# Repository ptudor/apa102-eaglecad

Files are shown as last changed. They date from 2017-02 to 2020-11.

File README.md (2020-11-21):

# apa102 controller

EAGLE schematic and board for apa102 controller

***
## the board

Top:

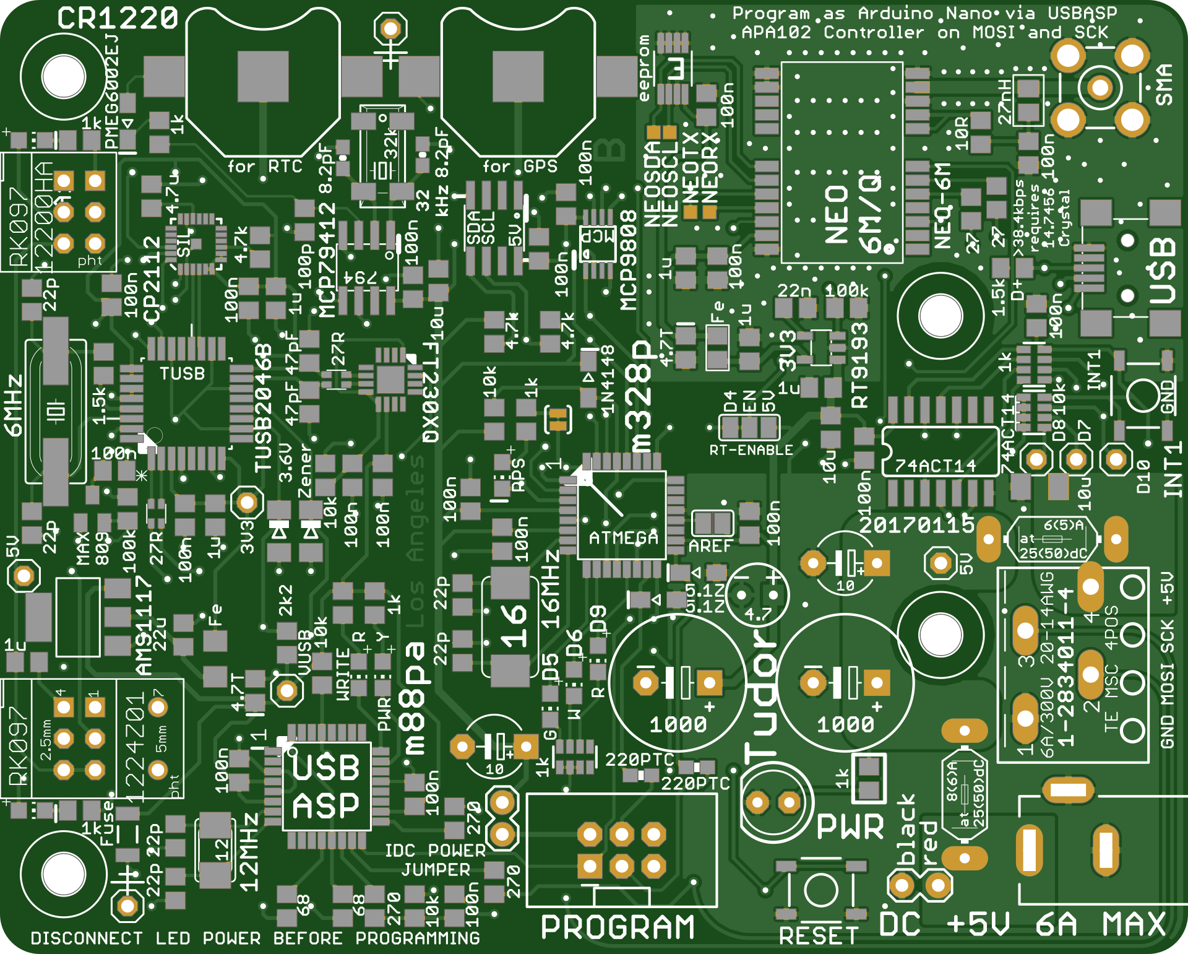
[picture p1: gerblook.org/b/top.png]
PNG of PCB top


Bottom:

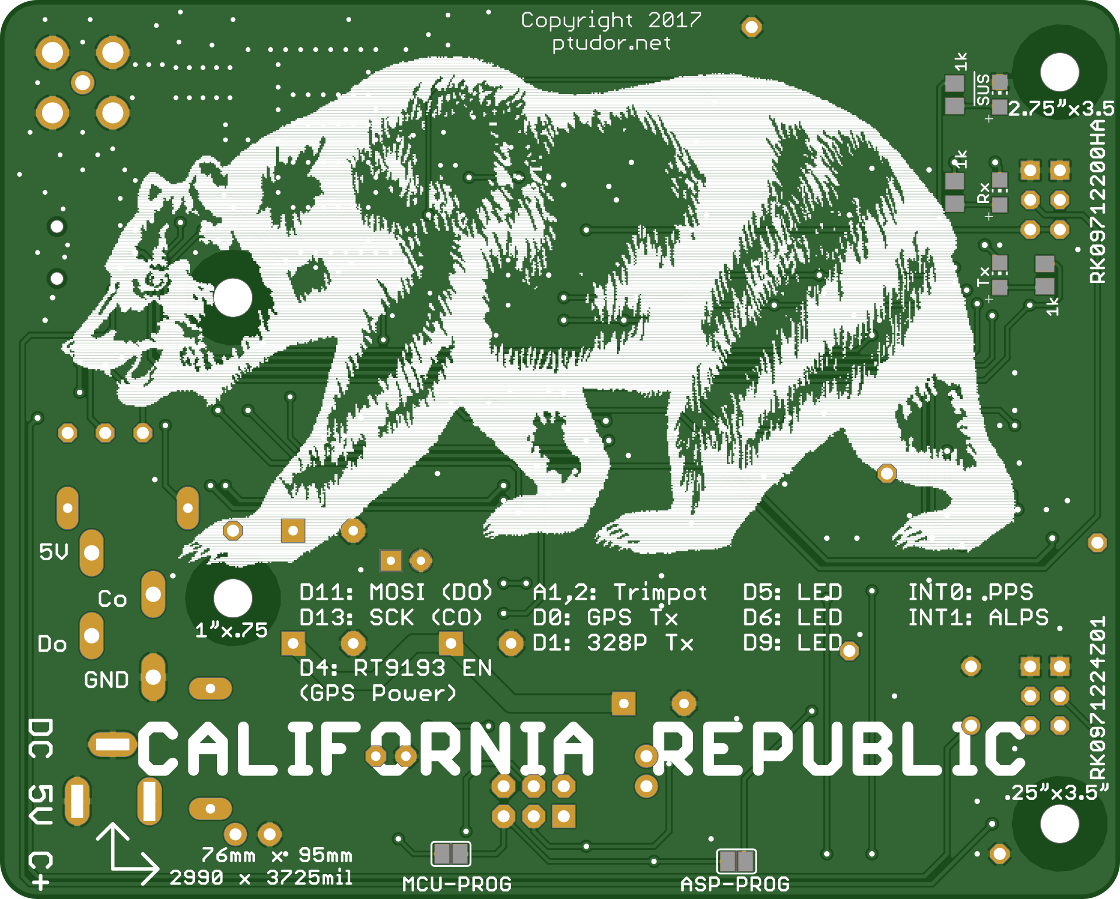
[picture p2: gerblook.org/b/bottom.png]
PNG of PCB bottom

***

## the schematic

#### Power:

DC 5V, AMS1117-3V3, RT9193GB-33.

There is no onboard 5V voltage regulator. Power is supplied by an external switched power supply at 5V with a 2.1mm center positive jack, in a common wall-wart or laptop brick form factor. Two options are available for providing power: Space for a standard rectangular PCB-mount DC jack exists and optionally, to keep those milled slots clean, two holes labelled "red" and "black" are available for use with circular panel mount DC jacks. A fuse follows the voltage input connectors and a second fuse sits between the regular 5V on the PCB and the 5V supplied to the LED connector. Two big electrolytic capacitors sit after the 5V in and before the MCU side and LED side of the power to hopefully prevent brownouts if a strip suddenly changes from off to fully illuminated.

When connected to external USB, the 5V-USB, after a fuse, powers the onboard atmega88p USBASP and FT230X serial directly and runs to an AMS1117 3.3v voltage regulator that serves the USB Hub, CP2112 i2c, and the USB enable on the uBlox GPS. The 3V3 output has the datasheet suggested 22uF capacitor.

The uBlox GPS is powered by an RT9193 3.3v voltage regulator. The enable pin of this device is connected to the primary MCU on pin D4 so it can be turned off in software. Alternatively, a solder jumper permits connecting the pin directly to the primary 5V. The RT9193 has the datasheet recommended 22nF capacitor on the bypass pin for low-noise operation and the 3V3 output passes though a ferrite bead and tantalum capacitor on its way to the integrated circuit.

#### GPS:

A standard uBlox NEO 7M occupies the upper right quadrant of the board. The numerous vias and general layout are hopefully compliant with datasheet requirements. The PPS and TX pins connect to the MCU with RX left disconnected. There is board space for an external eeprom, a cheap and simple part, but it is generally not required.

A CR1220 battery is dedicated to the GPS to enable warm starts. An SMA connection reminds us an external active antenna is required. While the mini-USB connector is nearby, it is not directly connected to the GPS.

#### USB-i2c:

The bridge the gap between computers and the hardware on the circuit board, a CP2112 offers access to the i2c bus.

#### RTC:

Preserving time across reboots, an MCP79408 or MCP79412 is set and periodically synchronized by the GPS. To decouple GPS time and RTC time, the RTC has its own battery so that even if GPS precision is delayed because of a dead-battery cold start, hopefully the RTC has a good idea of at least what the current minute is.

#### MCU:

Basically equivalent in function to an Arduino Nano, the heart of the board is its ATMega328p. It controls the input and output and all those things.

The chip runs at 16MHz with an external crystal. The MOSI and SCK pins are protected with 220 Ohm PTC fuses and 5.1V Zener diodes in the style of Ruggeduino.

Refer to the example program for further details.

#### ISP:

For convenience, an onboard USBASP programmer exists. During assembly and initial configuration be mindful of the solder jumpers on the underside of the PCB connected to the RESET pin of the 6-pin IDC ISP header and the two pins that when jumpered allow USB power to flow to the atmega328p target.

#### USB Hub:

After the board added a fourth USB connector, it became time to just add a hub, the Texas Instruments TUSB2046B. 27 Ohm resistors should be present in the correct places and absent where appropriate. A 1.5k Ohm resistor is connected between USB-3V3 and the external D+ line to signal the device as high speed USB. There is a MAX809S attached on the reset pin to provide the necessary pulse at startup.

#### USB Serial:

A cheaper alternative to the common FT232RL at half the price this board has a FT230X for simple debugging with serial print statements from the MCU. All data pins other than Transmit-Out are disconnected.

#### Connections:

Header for LEDs. Batteries. ISP. USB.

#### Switch Debouncing:

normal hex inverter

#### Input:

ALPS trimpot, ALPS trimpot with switch

#### Temp Sensor:

MCP9808

***

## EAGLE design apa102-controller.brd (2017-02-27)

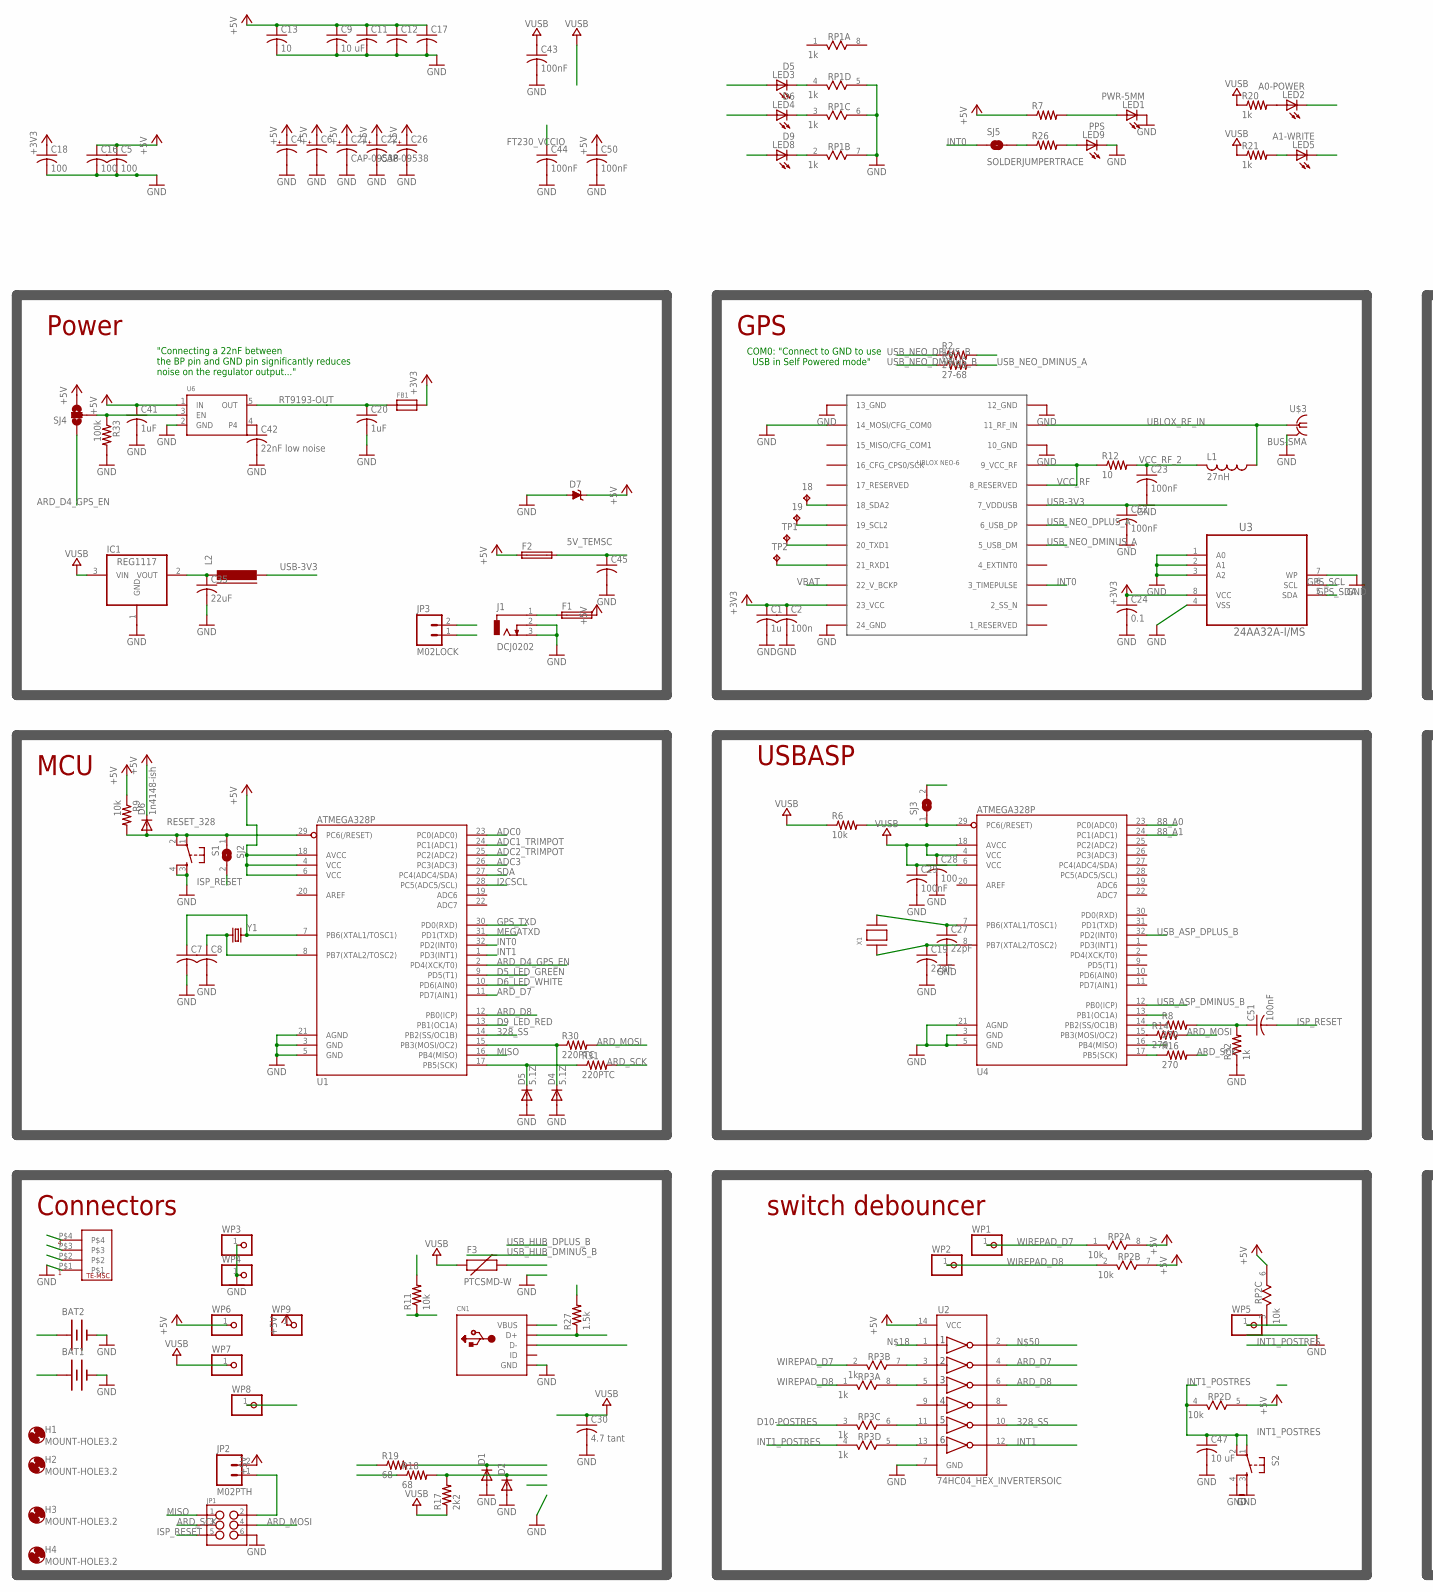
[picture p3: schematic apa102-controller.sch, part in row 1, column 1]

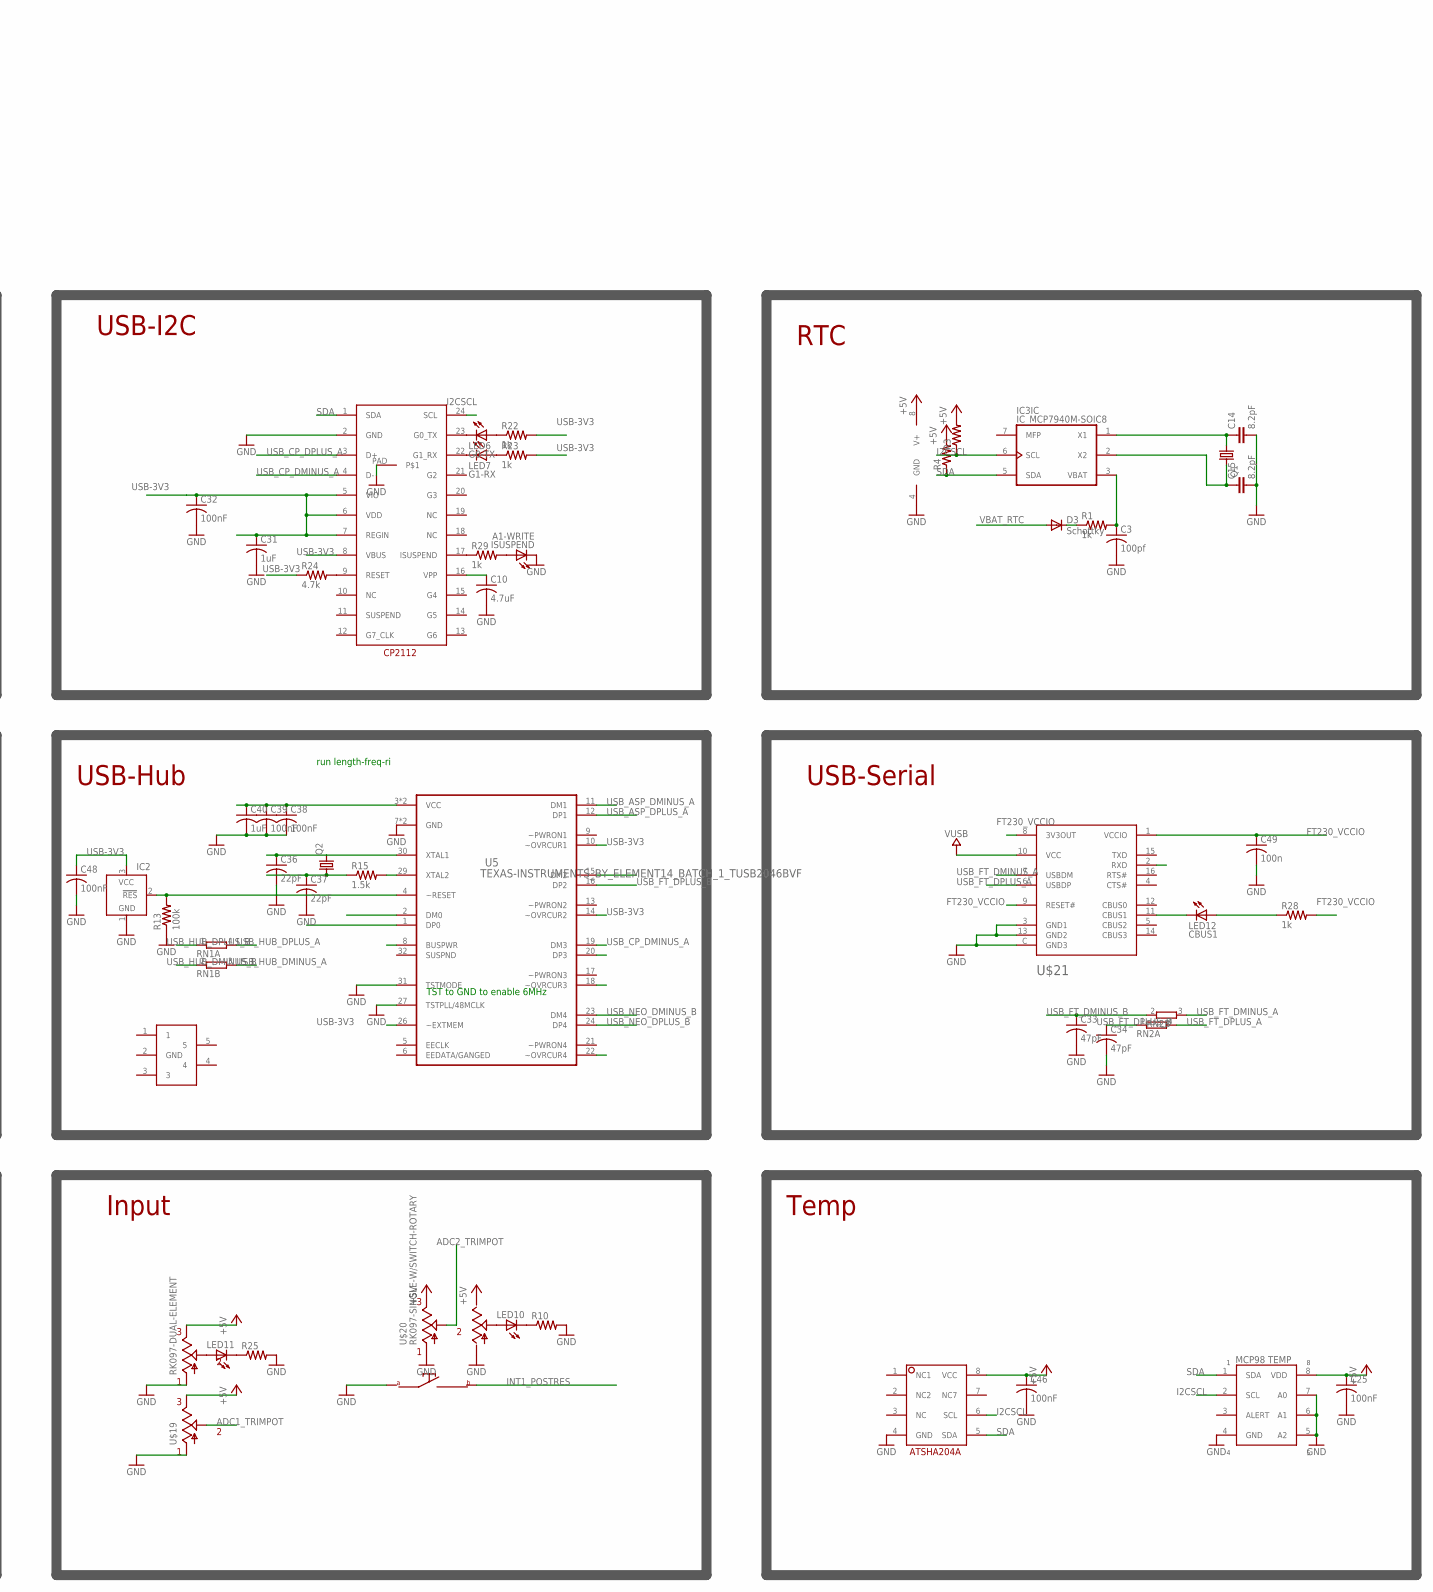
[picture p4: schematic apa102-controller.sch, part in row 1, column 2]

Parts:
18, 19: TPTP10SQ; TP10SQ
BAT1, BAT2: BATTERY12MM; BATTCON_12MM
C1: 1u; C0805
C2, C49: 100n; C0805
C3: 100pf; C0805
C4, C6: CPOL-USE5-5; E5-5
C5, C16, C18, C28: 100; C0805
C7, C8, C11, C12, C17: C-USC0805; C0805
C9, C47: 10 uF; C0805
C10: 4.7uF; C0805
C13: 10; C0805
C14, C15: 8.2pF; 0603-CAP
C19, C27, C36, C37: 22pF; C0805
C20, C31, C40, C41: 1uF; C0805
C21, C22: CAP-09538; CPOL-RADIAL-1000UF-25V
C23, C25, C29, C32, C38, C39, C43, C44, C46, C48, C50, C51, C52: 100nF; C0805
C24: 0.1; C0805
C26: 10UF-25V-20%(PTH)KIT; CPOL-RADIAL-10UF-25V-KIT
C30: 4.7 tant; C0805
C33, C34: 47pF; C0805
C35: 22uF; C0805
C42: 22nF low noise; C0805
C45: C-USC1206K; C1206K
CN1: USBMINIB; USB-MINIB
D1, D2: DIODE-MINIMELF; MINIMELF@1
D3: Schottky; SOD323-W@1
D4, D5: 5.1Z; SOD323-W@1
D6: 1n4148-ish; SOD323-W@1
D7: ZENER-DIODEDO41Z10; DO41Z10
F1, F2: LITTLEFUSE
F3: PTCSMD-W; PTC-1206-WIDE
FB1: FERRITE0805; 0805
H1, H2, H3, H4: MOUNT-HOLE3.2; 3,2
IC1: REG1117; SOT223
IC2: TCM809; SOT23B-3
IC3: IC_MCP7940M-SOIC8; SOIC-8
ISUSPEND: A1-WRITE; CHIP-LED0805
J1: DCJ0202
JP1: M03X2SHROUD; 2X3-SHROUDED
JP2: M02PTH; 1X02
JP3: M02LOCK; 1X02_LOCK
L1: 27nH; M0805
L2: FERRITE-1206; FB1206
LED1: PWR-5MM; LED5MM
LED2: A0-POWER; CHIP-LED0805
LED3: D5; CHIP-LED0805
LED4: D6; CHIP-LED0805
LED5: A1-WRITE; CHIP-LED0805
LED6: G0-TX; CHIP-LED0805
LED7: G1-RX; CHIP-LED0805
LED8: D9; CHIP-LED0805
LED9: PPS; CHIP-LED0805
LED10, LED11: LEDCHIP-LED0805; CHIP-LED0805
LED12: CBUS1; CHIP-LED0805
Q1: CRYSTALMM20SS; MM20SS
Q2: CRYSTALHC49UP; HC49UP
R1, R20, R21, R22, R23, R28, R29, R32: 1k; R0805
R2, R5: 27-68; R0805
R3, R4, R7, R10, R25, R26: R-US_R0805; R0805
R6, R9, R11: 10k; R0805
R8, R14, R16: 270; R0805
R12: 10; R0805
R13, R33: 100k; R0805
R15, R27: 1.5k; R0805
R17: 2k2; R0805
R18, R19: 68; R0805
R24: 4.7k; R0805
R30, R31: 220PTC; 0603-RES
RN1, RN2: 2R-NEXBV4V; EXBV4V
RP1, RP3: 1k; RES4NT
RP2: 10k; RES4NT
S1, S2: TAC_SWITCHSMD; TACTILE-SWITCH-SMD
SJ2, SJ3: SJ
SJ4: SOLDERJUMPER_2WAYT; SJ_2
SJ5: SOLDERJUMPERTRACE; SJ_2S-TRACE
TP1, TP2: TPTP10SQ; TP10SQ
U1, U4: ATMEGA328P; TQFP32-08
U2: 74HC04_HEX_INVERTERSOIC; SOIC-14
U3: 24AA32A-I/MS; SOP65P490X110-8N
U5: TEXAS-INSTRUMENTS_BY_ELEMENT14_BATCH_1_TUSB2046BVF; TEXAS-INSTRUMENTS_BY_ELEMENT14_BATCH_1_QFP80P900X900X145-32N
U6: VREG_SOT23-5; SOT23-5
U$2: UBLOX_NEO-6; UBLOX_NEO-6P
U$3: BUS-SMA
U$7: MCP98; MSOP08
U$11: CP2112; QFN-24
U$17: TE-MSC-4POS-6A
U$18: ATSHA204A; SO08
U$19: RK097-DUAL-ELEMENT
U$20: RK097-SINGLE-W/SWITCH-ROTARY; RK097-DUAL-ELEMENT-W/SWITCH
U$21: FT230XQ; QFN4X4-16
U$23: ESDTUDOR; SOT23-5L
WP1, WP2, WP3, WP4, WP5, WP6, WP7, WP8, WP9: WPAD-1-PTH; WPAD-1-PTH-2.54
X1: XTALNX5032; NX5032
Y1: CRYSTALABM2; CRYSTAL-ABRACON-ABM2

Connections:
5V_TEMSC: C45.1, F2.2, U$17.P$4
88_A0: LED2.C, U4.23 (PC0(ADC0))
88_A1: LED5.C, U4.24 (PC1(ADC1))
328_SS: U1.14 (PB2(SS/OC1B)), U2.10 (5Y)
+3V3: C1.1, C2.1, C18.1, C24.1, FB1.2, U3.8 (VCC), U$2.23_VCC
+5V: C4.+, C5.1, C6.+, C9.1, C11.1, C12.1, C13.1, C16.1, C17.1, C21.+, C22.+, C25.1, C26.1 (+), C41.1, C46.1, C50.1, D6.C, D7.C, F1.2, F2.1, IC3.8 (V+), JP2.2, R3.2, R4.2, R7.1, R9.1, RP2.5 (2), RP2.6 (2), RP2.7 (2), RP2.8 (2), SJ4.3, U1.4 (VCC), U1.6 (VCC), U1.18 (AVCC), U2.14 (VCC), U6.1 (IN), U$7.8 (VDD), U$18.8 (VCC), U$19.P$3 (E1), U$19.P$6 (E), U$20.P$3 (E), U$20.P$6 (E1), WP6.1, WP9.1
ADC0: U1.23 (PC0(ADC0))
ADC1_TRIMPOT: U1.24 (PC1(ADC1)), U$19.P$5 (S1)
ADC2_TRIMPOT: U1.25 (PC2(ADC2)), U$20.P$2 (S)
ADC3: U1.26 (PC3(ADC3))
ARD_D4_GPS_EN: R33.1, SJ4.1, SJ4.2, U1.2 (PD4(XCK/T0)), U6.3 (EN)
ARD_D7: U1.11 (PD7(AIN1)), U2.4 (2Y)
ARD_D8: U1.12 (PB0(ICP)), U2.6 (3Y)
ARD_MOSI: JP1.4, R14.2, R30.2, U$17.P$2
ARD_SCK: JP1.3, R16.2, R31.2, U$17.P$3
D5_LED_GREEN: LED3.A, U1.9 (PD5(T1))
D6_LED_WHITE: LED4.A, U1.10 (PD6(AIN0))
D9_LED_RED: LED8.A, U1.13 (PB1(OC1A))
D10-POSTRES: RP2.3 (1), RP3.3 (1), WP5.1
DCJACK_TO_PTC: F1.1, J1.1, JP3.1
FT230_VCCIO: C44.1, C49.1, R11.2, R28.2, U$21.1 (VCCIO), U$21.8 (3V3OUT), U$21.9 (RESET#)
FT_CB0: LED12.C, U$21.11 (CBUS1)
GND: BAT1.GND (-), BAT2.GND (-), C1.2, C2.2, C3.2, C4.-, C5.2, C6.-, C7.2, C8.2, C9.2, C10.2, C11.2, C12.2, C13.2, C14.2, C15.2, C16.2, C17.2, C18.2, C19.2, C20.2, C21.-, C22.-, C23.2, C24.2, C25.2, C26.2 (-), C27.2, C28.2, C29.2, C30.2, C31.2, C32.2, C33.2, C34.2, C35.2, C36.2, C37.2, C38.2, C39.2, C40.2, C41.2, C42.2, C43.2, C44.2, C45.2, C46.2, C47.2, C48.2, C49.2, C50.2, C52.2, CN1.GND, D1.A, D2.A, D4.A, D5.A, D7.A, IC1.1 (GND), IC2.1 (GND), IC3.4 (GND), ISUSPEND.C, J1.2, J1.3, JP1.6, JP3.2, LED1.K (C), LED9.C, R10.2, R13.1, R25.2, R32.1, R33.2, RP1.5 (2), RP1.6 (2), RP1.7 (2), S1.3, S1.4, S2.3, S2.4, U1.3 (GND), U1.5 (GND), U1.21 (AGND), U2.7 (GND), U3.1 (A0), U3.2 (A1), U3.3 (A2), U3.4 (VSS), U3.7 (WP), U4.3 (GND), U4.5 (GND), U4.21 (AGND), U5.7 (GND), U5.27 (TSTPLL/48MCLK), U5.28 (GND), U5.31 (TSTMODE), U6.2 (GND), U$2.10_GND, U$2.12_GND, U$2.13_GND, U$2.14_MOSI/CFG_COM0, U$2.24_GND, U$3.2 (GND), U$3.3 (GND), U$3.4 (GND), U$3.5 (GND), U$7.4 (GND), U$7.5 (A2), U$7.6 (A1), U$7.7 (A0), U$11.2 (GND), U$11.PAD, U$17.P$1, U$18.4 (GND), U$19.P$1 (A1), U$19.P$4 (A), U$20.P$1 (A), U$20.P$4 (A1), U$20.P$7 (SW1), U$21.3 (GND1), U$21.13 (GND2), U$21.C (GND3), WP3.1, WP4.1
GPS_RXD: TP2.TP, U$2.21_RXD1
GPS_SCL: 19.TP, U3.6 (SCL), U$2.19_SCL2
GPS_SDA: 18.TP, U3.5 (SDA), U$2.18_SDA2
GPS_TXD: TP1.TP, U1.30 (PD0(RXD)), U$2.20_TXD1
HEX3: RP3.7 (2), U2.3 (2A)
HEX5: RP3.8 (2), U2.5 (3A)
HEX11: RP3.6 (2), U2.11 (5A)
HEX13: RP3.5 (2), U2.13 (6A)
I2CSCL: IC3.6 (SCL), R3.1, U1.28 (PC5(ADC5/SCL)), U$7.2 (SCL), U$11.24 (SCL), U$18.6 (SCL)
INT0: SJ5.1, U1.32 (PD2(INT0)), U$2.3_TIMEPULSE
INT1: U1.1 (PD3(INT1)), U2.12 (6Y)
INT1_POSTRES: C47.1, RP2.4 (1), RP3.4 (1), S2.1, S2.2, U$20.P$8 (SW2)
ISP_RESET: C51.2, JP1.5, SJ2.2, SJ3.2
MEGATXD: R11.1, U1.31 (PD1(TXD)), U$21.2 (RXD)
MISO: JP1.1, U1.16 (PB4(MISO)), U4.16 (PB4(MISO))
unnamed: C3.1, IC3.3 (VBAT), R1.2
unnamed: D3.C, R1.1
unnamed: C35.1, IC1.2 (VOUT), L2.1
unnamed: LED10.A, U$20.P$5 (S1)
unnamed: C42.1, U6.4
unnamed: LED1.A, R7.2
unnamed: D4.C, R30.1, U1.15 (PB3(MOSI/OC2))
unnamed: IC2.2 (!RES), R13.2, U5.4 (~RESET)
unnamed: C7.1, U1.7 (PB6(XTAL1/TOSC1)), Y1.P$2 (2)
unnamed: C8.1, U1.8 (PB7(XTAL2/TOSC2)), Y1.P$1 (1)
unnamed: C14.1, IC3.1 (X1), Q1.1
unnamed: C15.1, IC3.2 (X2), Q1.4 (2)
unnamed: LED3.C, RP1.4 (1)
unnamed: LED4.C, RP1.3 (1)
unnamed: LED10.C, R10.1
unnamed: R15.2, U5.29 (XTAL2)
unnamed: LED11.A, U$19.P$2 (S)
unnamed: LED11.C, R25.1
unnamed: LED6.C, U$11.23 (G0_TX)
unnamed: LED7.C, U$11.22 (G1_RX)
unnamed: R6.2, SJ3.1, U4.29 (PC6(/RESET))
unnamed: C19.1, U4.8 (PB7(XTAL2/TOSC2)), X1.P$1
unnamed: C27.1, U4.7 (PB6(XTAL1/TOSC1)), X1.P$2
unnamed: R8.1, U4.14 (PB2(SS/OC1B))
unnamed: R14.1, U4.15 (PB3(MOSI/OC2))
unnamed: R16.1, U4.17 (PB5(SCK))
unnamed: C36.1, Q2.2, U5.30 (XTAL1)
unnamed: C37.1, Q2.1, R15.1
unnamed: JP1.2, JP2.1
unnamed: LED2.A, R20.2
unnamed: LED5.A, R21.2
unnamed: LED6.A, R22.1
unnamed: LED7.A, R23.1
unnamed: R24.2, U$11.9 (RESET)
unnamed: C10.1, U$11.16 (VPP)
unnamed: R29.1, U$11.17 (ISUSPEND)
unnamed: LED8.C, RP1.2 (1)
unnamed: ISUSPEND.A, R29.2
unnamed: D5.C, R31.1, U1.17 (PB5(SCK))
unnamed: LED9.A, R26.2
unnamed: R26.1, SJ5.2
unnamed: C51.1, R8.2, R32.2
unnamed: LED12.A, R28.1
RESET_328: D6.A, R9.2, S1.1, S1.2, SJ2.1, U1.29 (PC6(/RESET))
RT9193-OUT: C20.1, FB1.1, U6.5 (OUT)
SDA: IC3.5 (SDA), R4.1, U1.27 (PC4(ADC4/SDA)), U$7.1 (SDA), U$11.1 (SDA), U$18.5 (SDA)
UBLOX_RF_IN: L1.1, U$2.11_RF_IN, U$3.1
USB-3V3: C31.1, C32.1, C38.1, C39.1, C40.1, C48.1, C52.1, IC2.3 (VCC), L2.2, R22.2, R23.2, R24.1, R27.2, U5.3 (VCC), U5.8 (BUSPWR), U5.10 (~OVRCUR1), U5.14 (~OVRCUR2), U5.18 (~OVRCUR3), U5.22 (~OVRCUR4), U5.25 (VCC), U5.26 (~EXTMEM), U$2.7_VDDUSB, U$11.5 (VIO), U$11.6 (VDD), U$11.7 (REGIN), U$11.8 (VBUS), WP8.1
USB_ASP_DMINUS_A: D2.C, R17.2, R18.2, U5.11 (DM1)
USB_ASP_DMINUS_B: R18.1, U4.12 (PB0(ICP))
USB_ASP_DPLUS_A: D1.C, R19.2, U5.12 (DP1)
USB_ASP_DPLUS_B: R19.1, U4.13 (PB1(OC1A)), U4.32 (PD2(INT0))
USB_CP_DMINUS_A: U5.19 (DM3), U$11.4 (D-)
USB_CP_DPLUS_A: U5.20 (DP3), U$11.3 (D+)
USB_FT_DMINUS_A: RN2.3 (2), U$21.7 (USBDM)
USB_FT_DMINUS_B: C33.1, RN2.2 (1), U5.15 (DM2)
USB_FT_DPLUS_A: RN2.4 (2), U$21.6 (USBDP)
USB_FT_DPLUS_B: C34.1, RN2.1, U5.16 (DP2)
USB_HUB_DMINUS_A: RN1.3 (2), U5.2 (DM0)
USB_HUB_DMINUS_B: CN1.D-, RN1.2 (1)
USB_HUB_DPLUS_A: RN1.4 (2), U5.1 (DP0)
USB_HUB_DPLUS_B: CN1.D+, R27.1, RN1.1
USB_NEO_DMINUS_A: R5.2, U$2.5_USB_DM
USB_NEO_DMINUS_B: R5.1, U5.23 (DM4)
USB_NEO_DPLUS_A: R2.2, U$2.6_USB_DP
USB_NEO_DPLUS_B: R2.1, U5.24 (DP4)
USB_RAW_5V: CN1.VBUS, F3.2
VBAT: BAT1.PWR@1 (+), U$2.22_V_BCKP
VBAT_RTC: BAT2.PWR@1 (+), D3.A
VCC_RF: R12.1, U$2.8_RESERVED, U$2.9_VCC_RF
VCC_RF_2: C23.1, L1.2, R12.2
VUSB: C28.1, C29.1, C30.1, C43.1, F3.1, IC1.3 (VIN), R6.1, R17.1, R20.1, R21.1, U4.4 (VCC), U4.6 (VCC), U4.18 (AVCC), U$21.10 (VCC), WP7.1
WIREPAD_D7: RP2.1, RP3.2 (1), WP1.1
WIREPAD_D8: RP2.2 (1), RP3.1, WP2.1

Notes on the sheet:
COM0: "Connect to GND to use USB in Self Powered mode"
TST to GND to enable 6MHz
Connectors
Power
Input
MCU
USB-Serial
USB-Hub
USB-I2C
GPS
RTC
Temp
USBASP
switch debouncer
"Connecting a 22nF between the BP pin and GND pin significantly reduces noise on the regulator output..."
run length-freq-ri

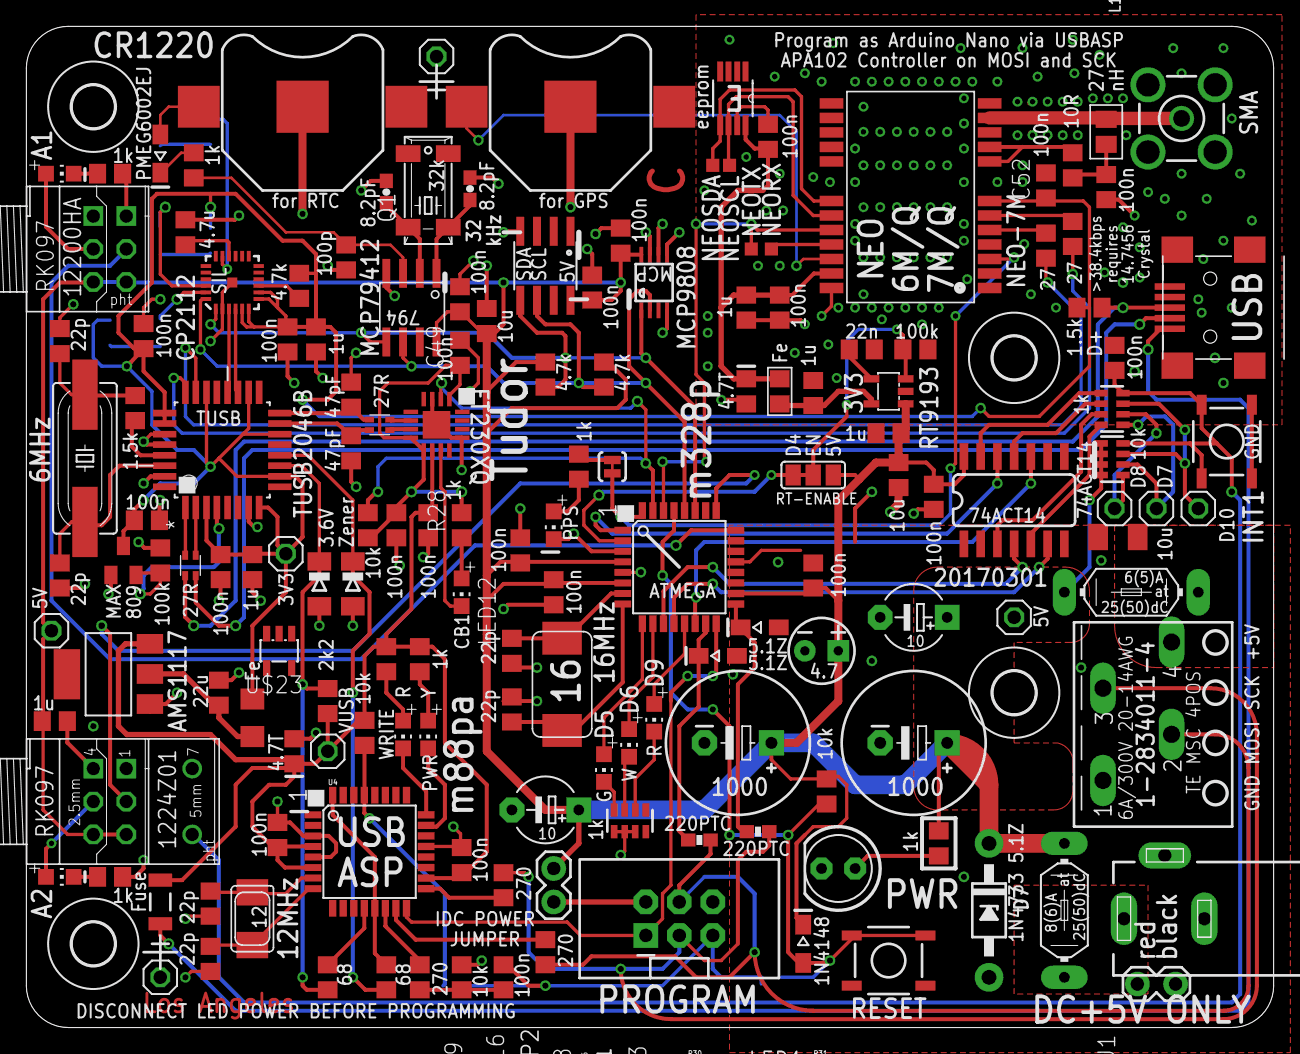
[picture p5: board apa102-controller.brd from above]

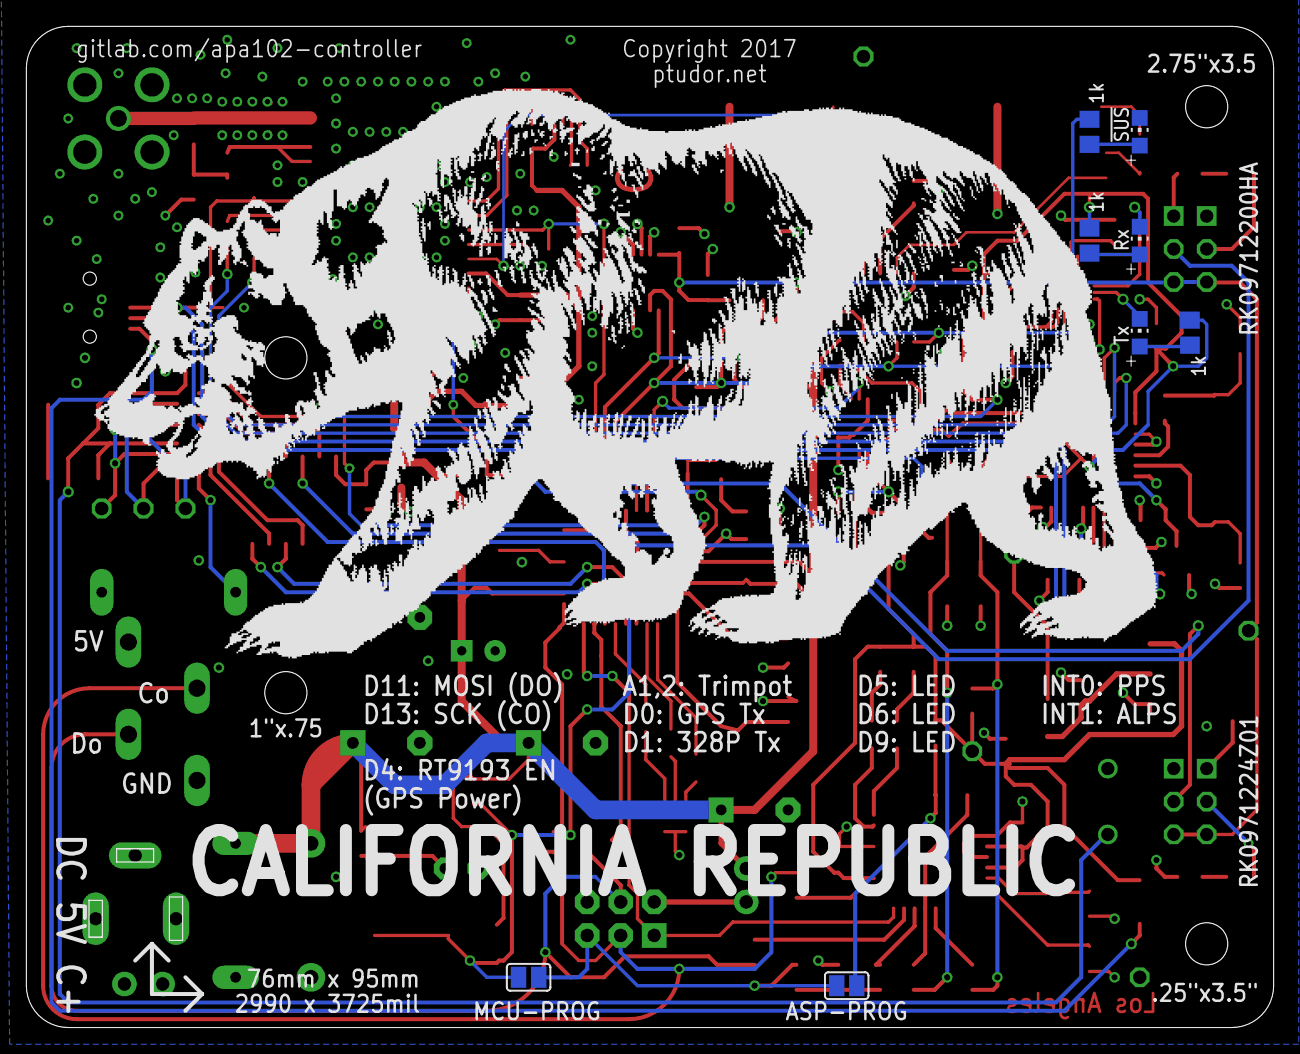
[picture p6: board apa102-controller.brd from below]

Board: 2 copper layers, 94.6 x 75.9 mm, 170 parts (9 on the bottom side), 110 nets.

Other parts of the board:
U$1: BEARMED200DPI

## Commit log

2017-02-05 more labels
    [apa102-controller.brd, apa102-controller.sch]
2017-02-09 pcbs 20170206
    [apa102-controller.brd, apa102-controller.sch]
2017-02-25 add 1N4733 Zener
    [apa102-controller.brd, apa102-controller.sch]

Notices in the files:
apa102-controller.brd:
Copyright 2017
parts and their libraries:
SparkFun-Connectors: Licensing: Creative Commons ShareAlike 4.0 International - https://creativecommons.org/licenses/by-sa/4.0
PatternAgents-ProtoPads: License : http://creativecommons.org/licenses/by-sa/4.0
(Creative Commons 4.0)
